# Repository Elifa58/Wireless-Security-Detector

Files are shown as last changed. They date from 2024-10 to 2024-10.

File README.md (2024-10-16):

# Wireless-Security-Detector
I designed a PCB described in a course I took on the Udemy platform in September 2022. With this course, I designed a PCB namely Wireless Security Detector.

In this project, I learned many things such as component selection criterias, creating my own 3D model, creating a template for the schematic page, working with the STM32CubeMx program, information about stackup and vias, information about differential lines, adding logos to the PCB, teardrops feature, creating variants, panelization and obtaining production outputs.

The requirements of the designed card are as follows:
The card should be able to work with 220V AC 50 Hz Turkey home network connection. There should be 12V DC and 5V DC power outputs that the user can use from the system. The system should be able to connect to the computer with a USB interface and transfer data. The system should be able to provide real-time clock information to the user. The system should be able to instantly transfer ambient temperature data to the user. The system should be able to send data to the user when a movement is detected. When a movement is detected, the user can receive an audio or visual warning if they wish. The system should have a security camera view in the environment where the movement will be detected. The system will also be able to send all data to the user with its Wi-Fi feature. The user will be able to intervene in the software running in the processor if they wish.

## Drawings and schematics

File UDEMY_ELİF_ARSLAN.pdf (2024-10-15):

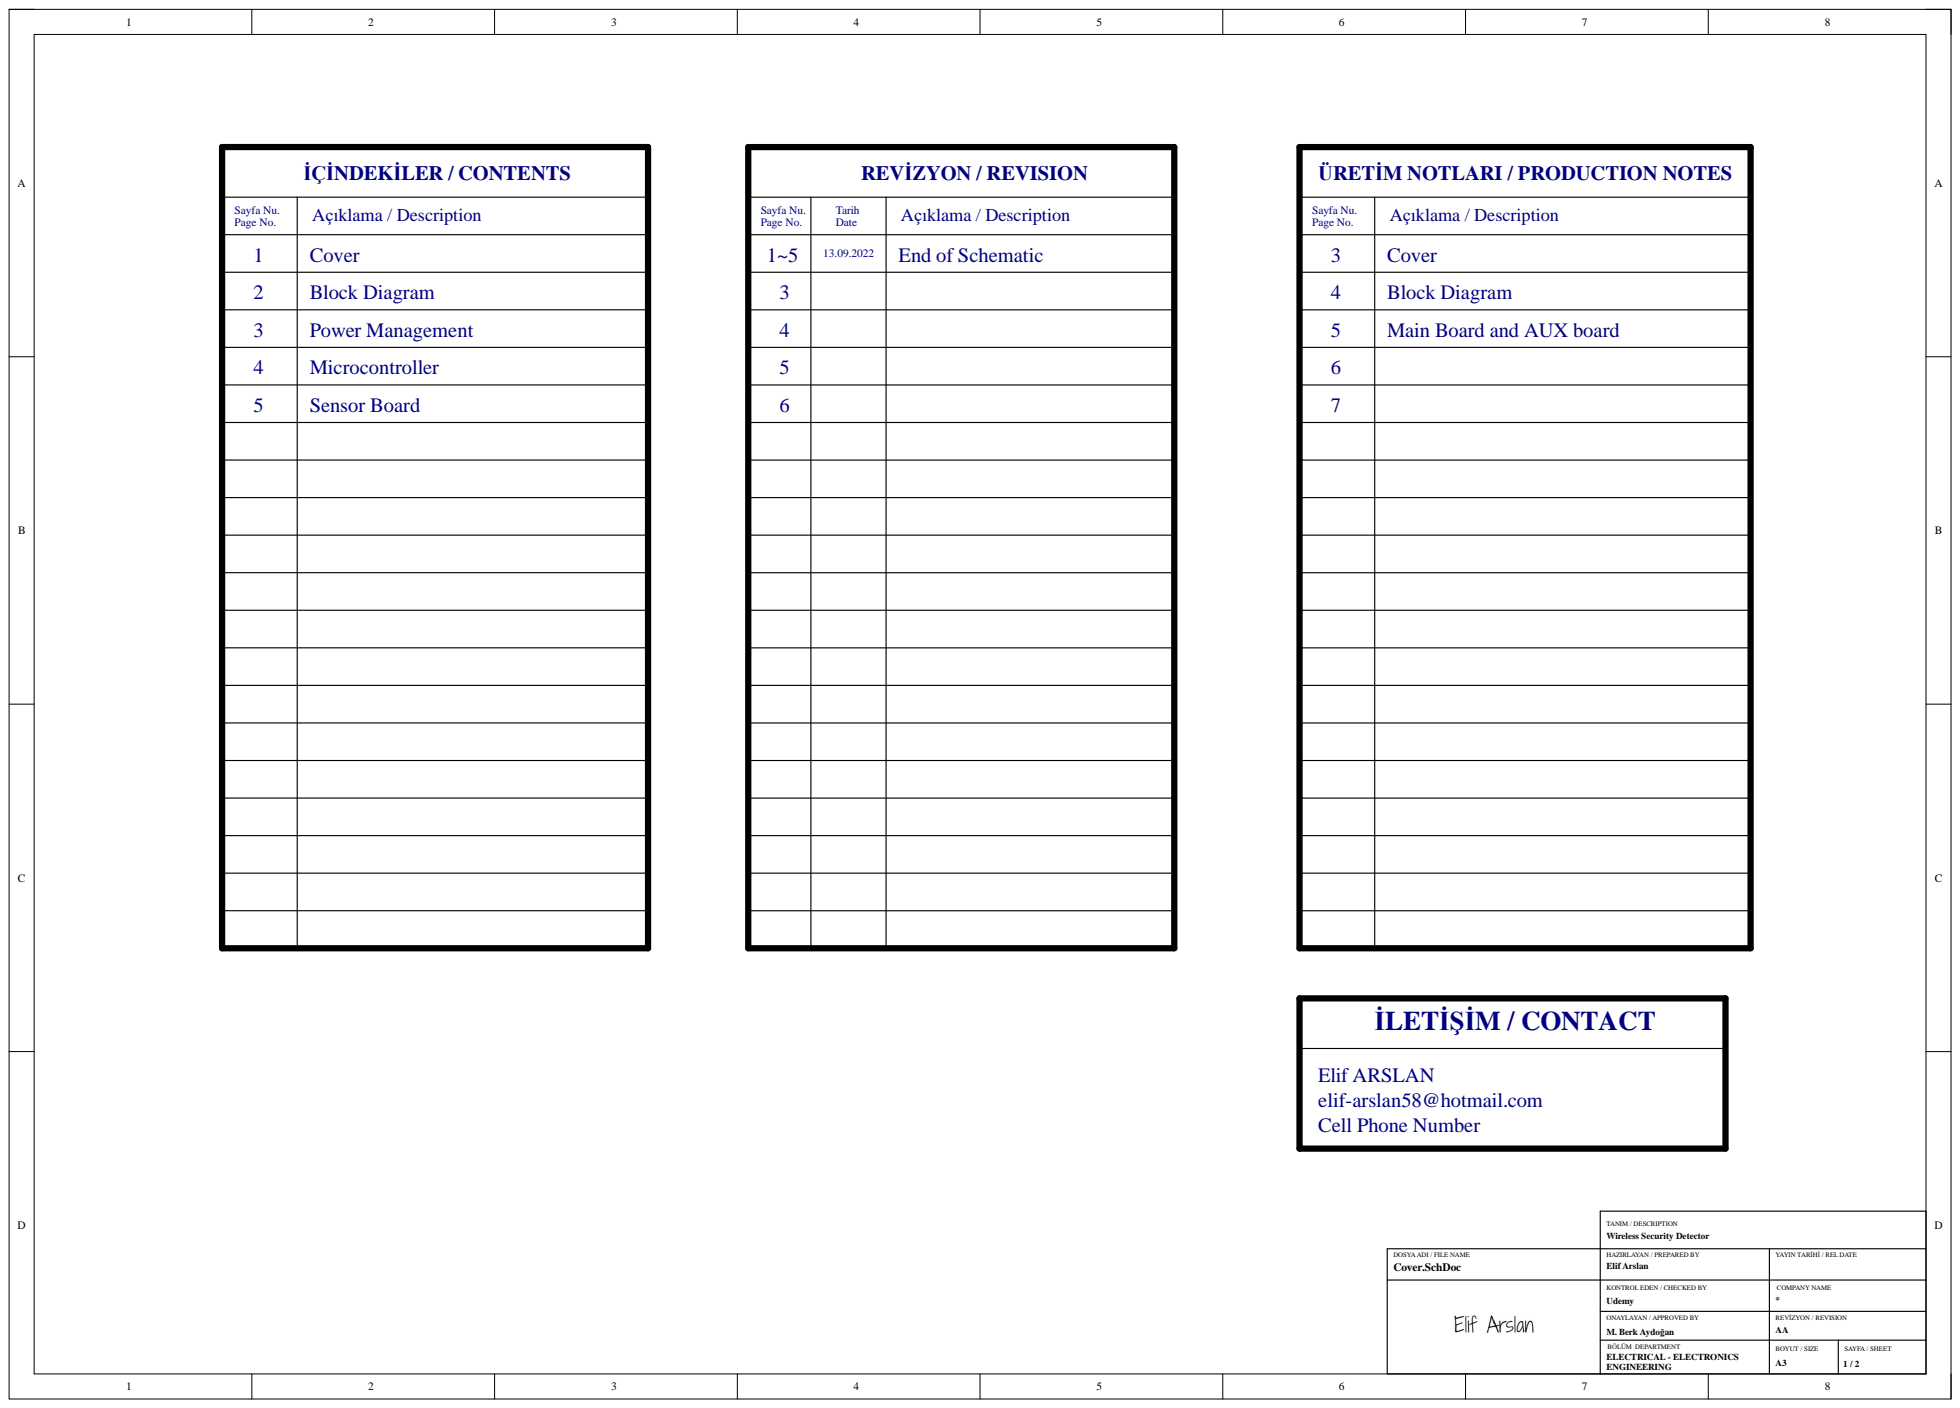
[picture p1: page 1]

ÜRETİM NOTLARI / PRODUCTION NOTES

Main Board and AUX board

DOSYA ADI / FILE NAME Cover.SchDoc | HAZIRLAYAN / PREPARED BY Elif Arslan | YAYIN TARİHİ / REL DATE

KONTROL EDEN / CHECKED BY Udemy | COMPANY NAME *

ONAYLAYAN / APPROVED BY M. Berk Aydoğan | REVİZYON / REVISION AA

BÖLÜM DEPARTMENT ELECTRICAL - ELECTRONICS ENGINEERING | BOYUT / SIZE A3 | SAYFA / SHEET 1 / 2

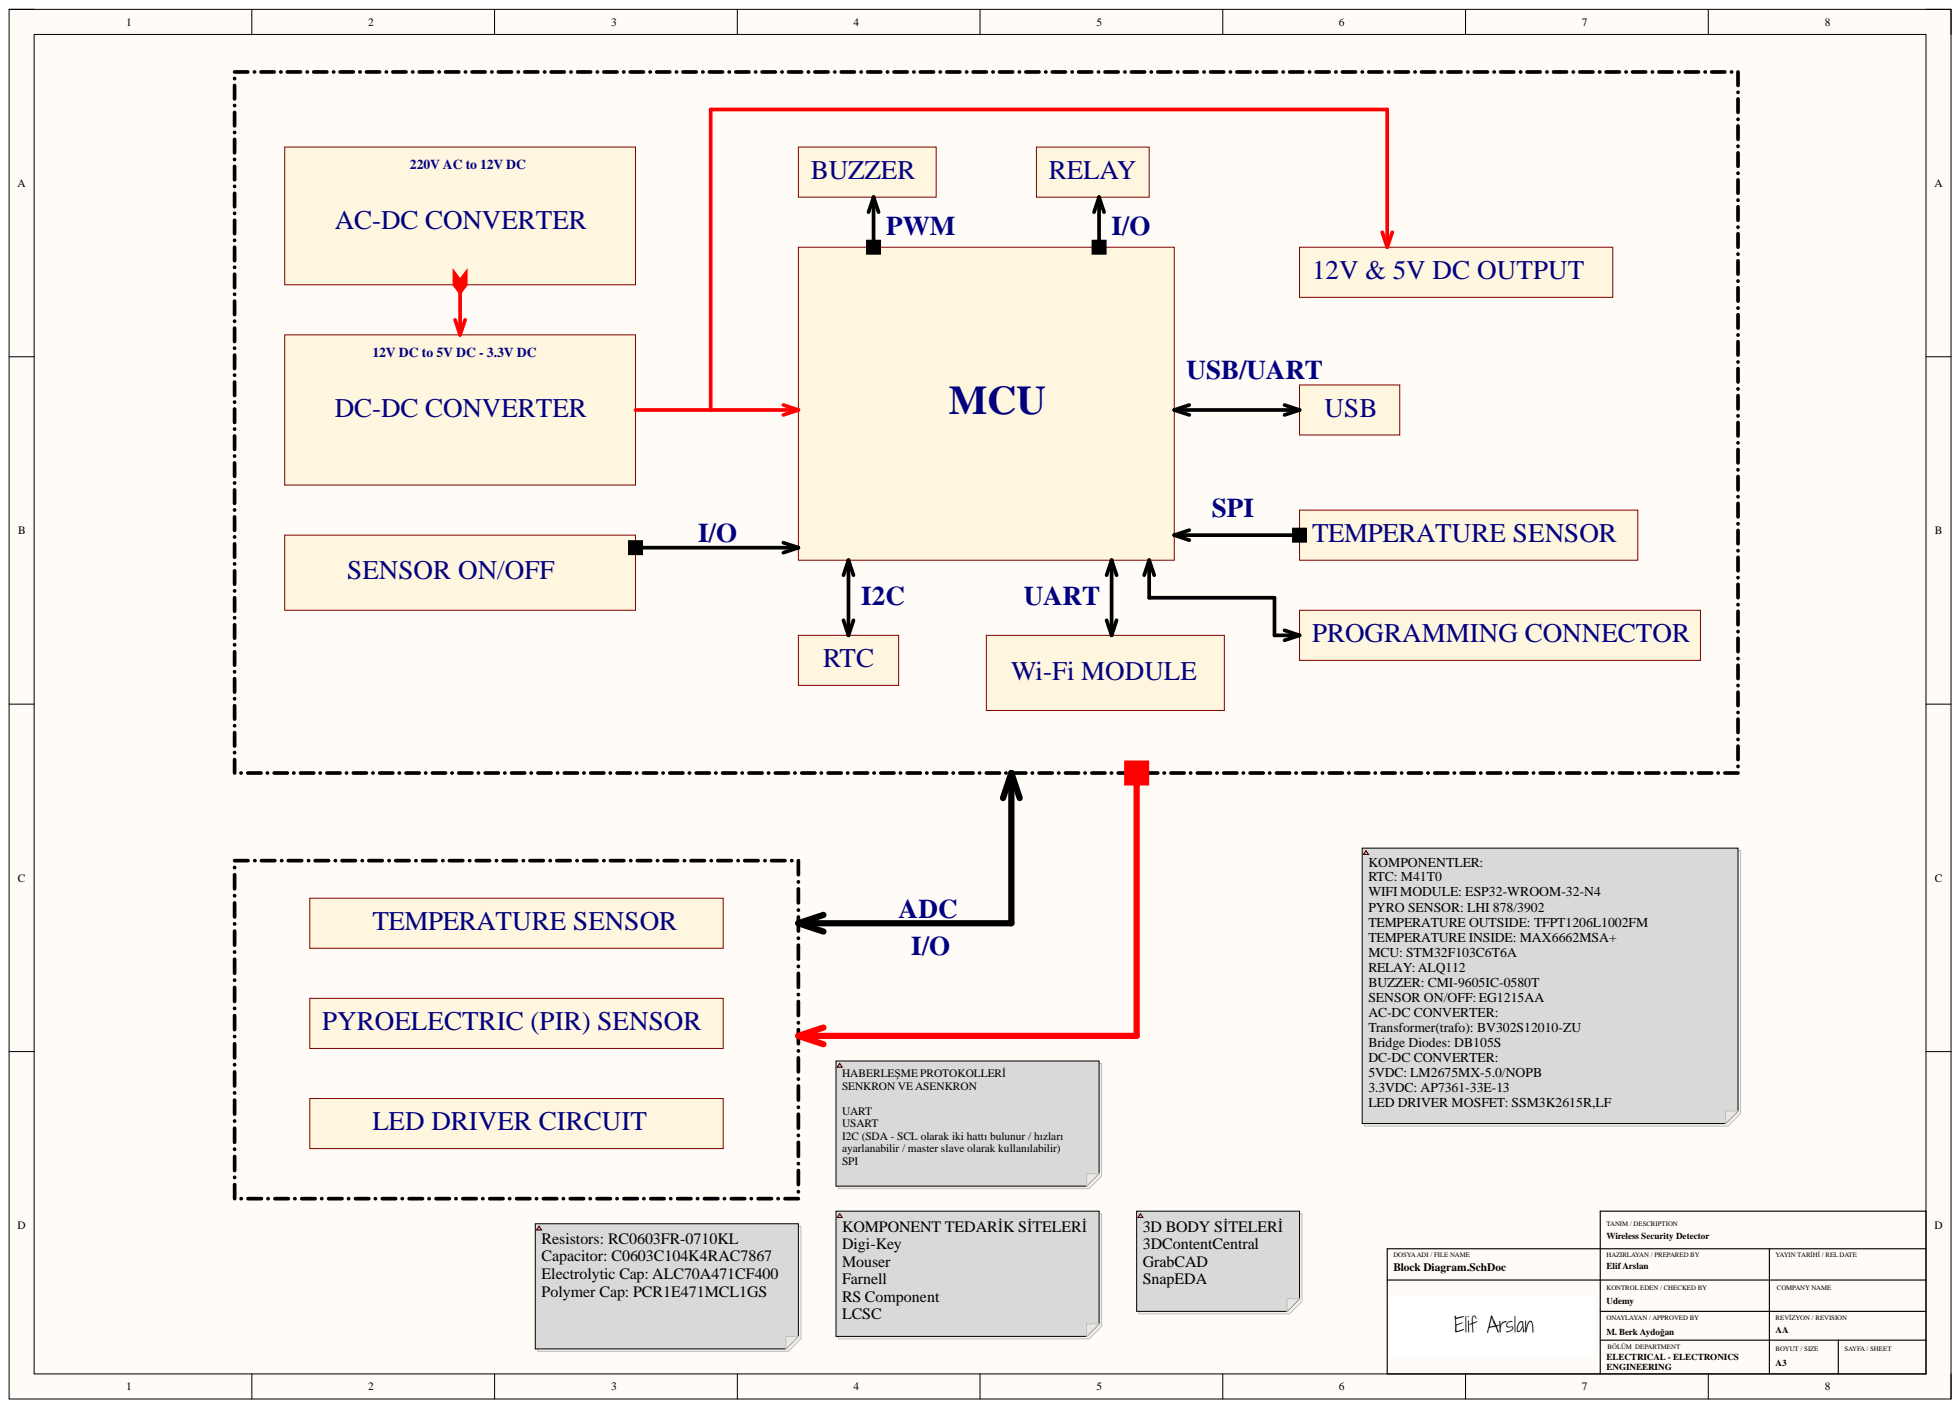
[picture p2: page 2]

KOMPONENTLER:
RTC: M41T0
WIFI MODULE: ESP32-WROOM-32-N4
PYRO SENSOR: LHI 878/3902
TEMPERATURE OUTSIDE: TFPT1206L1002FM
TEMPERATURE INSIDE: MAX6662MSA+
MCU: STM32F103C6T6A
RELAY: ALQ112
BUZZER: CMI-9605IC-0580T
SENSOR ON/OFF: EG1215AA
AC-DC CONVERTER:
Transformer(trafo): BV302S12010-ZU
Bridge Diodes: DB105S
DC-DC CONVERTER:
5VDC: LM2675MX-5.0/NOPB
3.3VDC: AP7361-33E-13
LED DRIVER MOSFET: SSM3K2615R,LF

UART
USART
I2C (SDA - SCL olarak iki hattı bulunur / hızları
ayarlanabilir / master slave olarak kullanılabilir)
SPI

DOSYA ADI / FILE NAME Block Diagram.SchDoc | HAZIRLAYAN / PREPARED BY Elif Arslan | YAYIN TARİHİ / REL DATE

KONTROL EDEN / CHECKED BY | COMPANY NAME

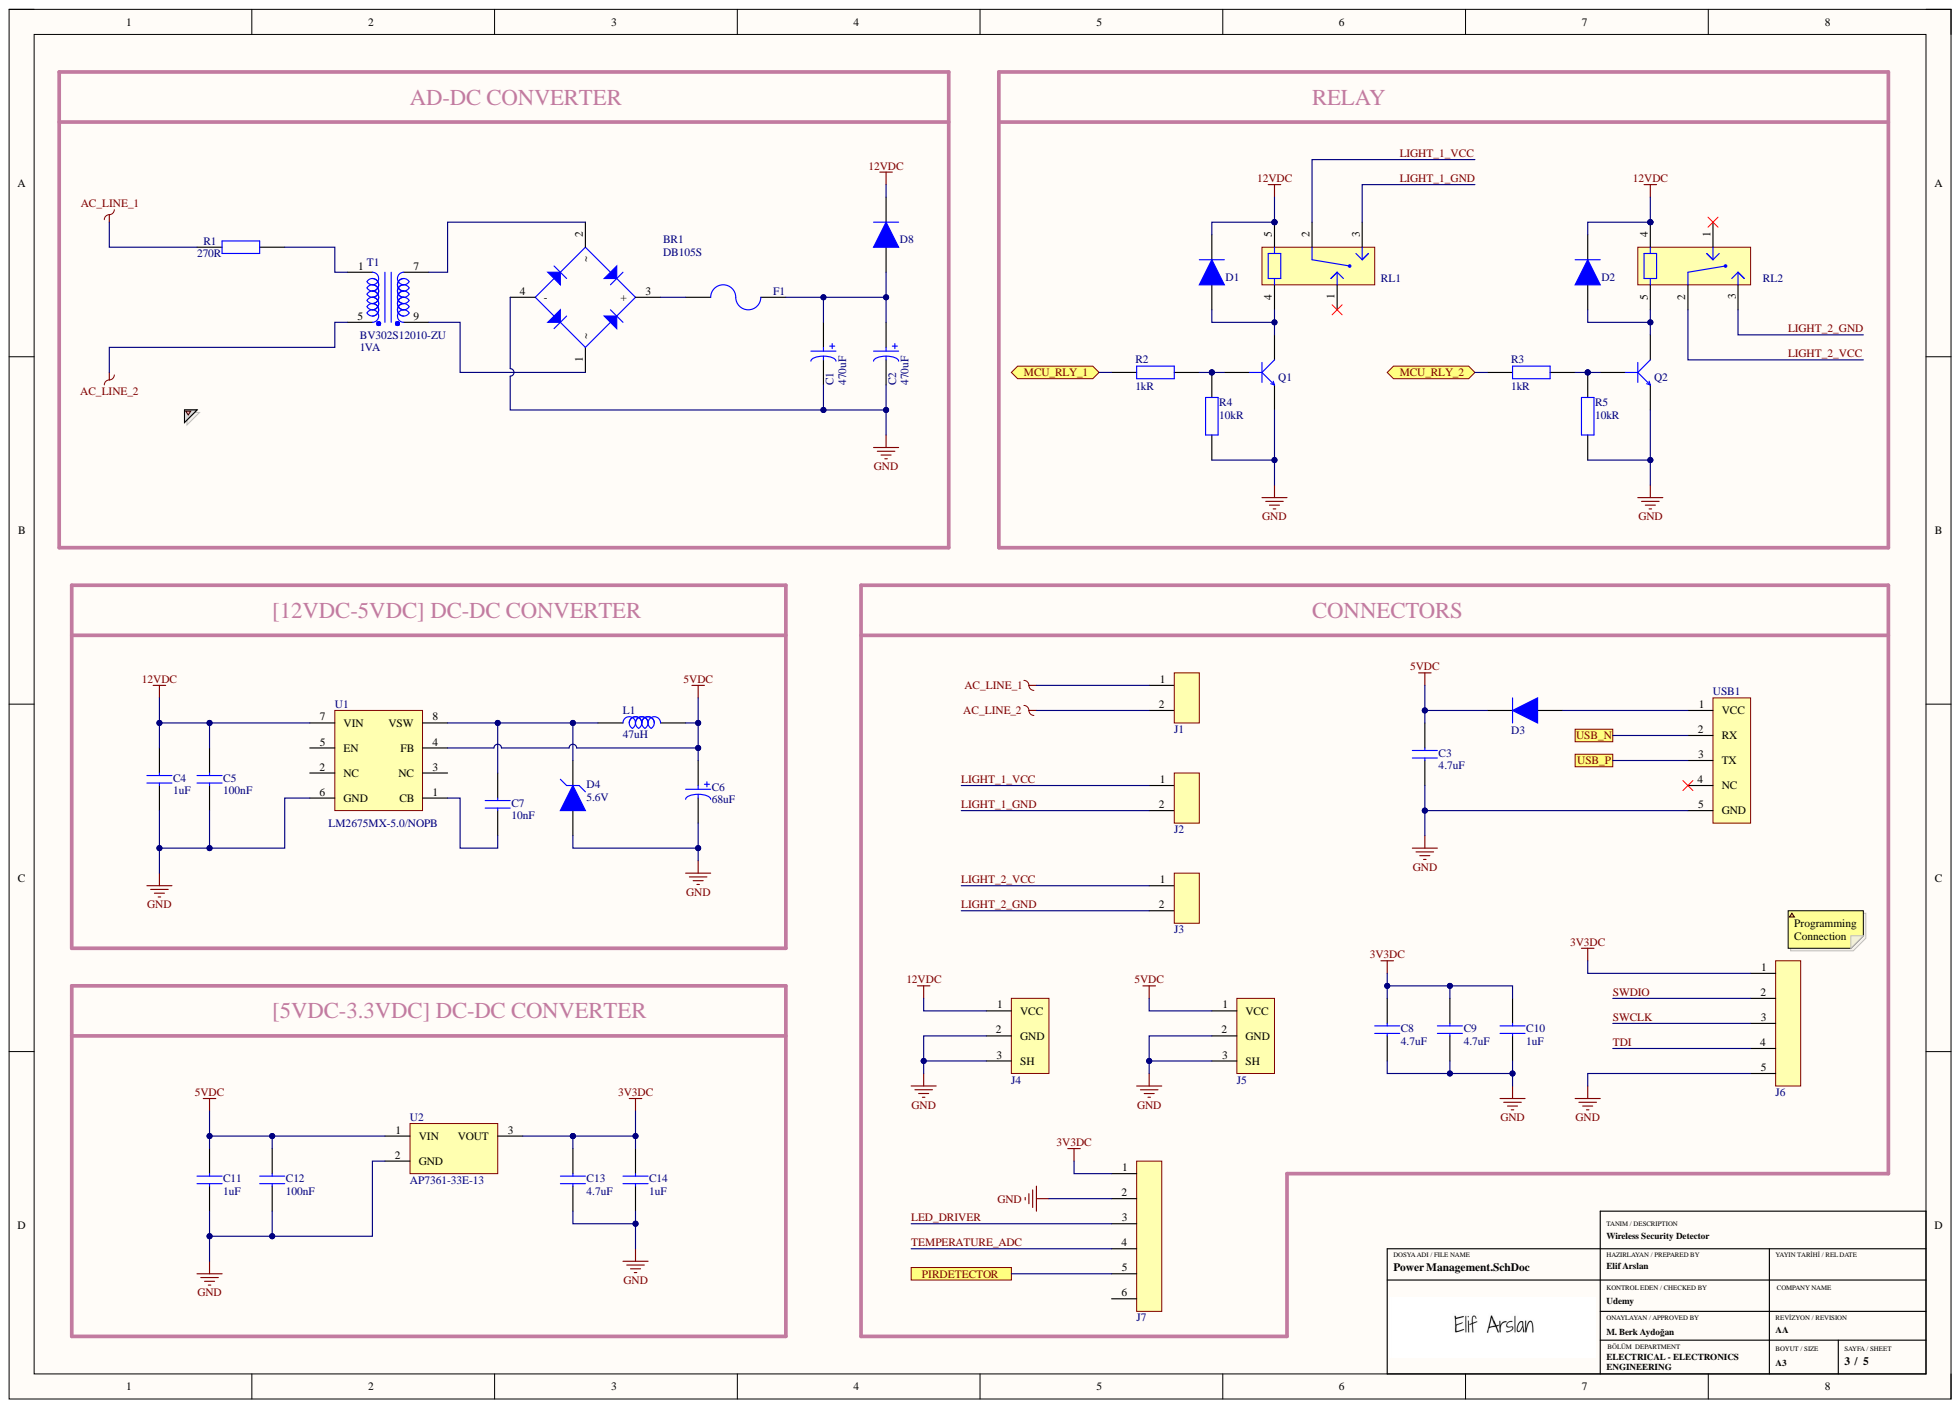
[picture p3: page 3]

USB_P | NC 4

KONTROL EDEN / CHECKED BY

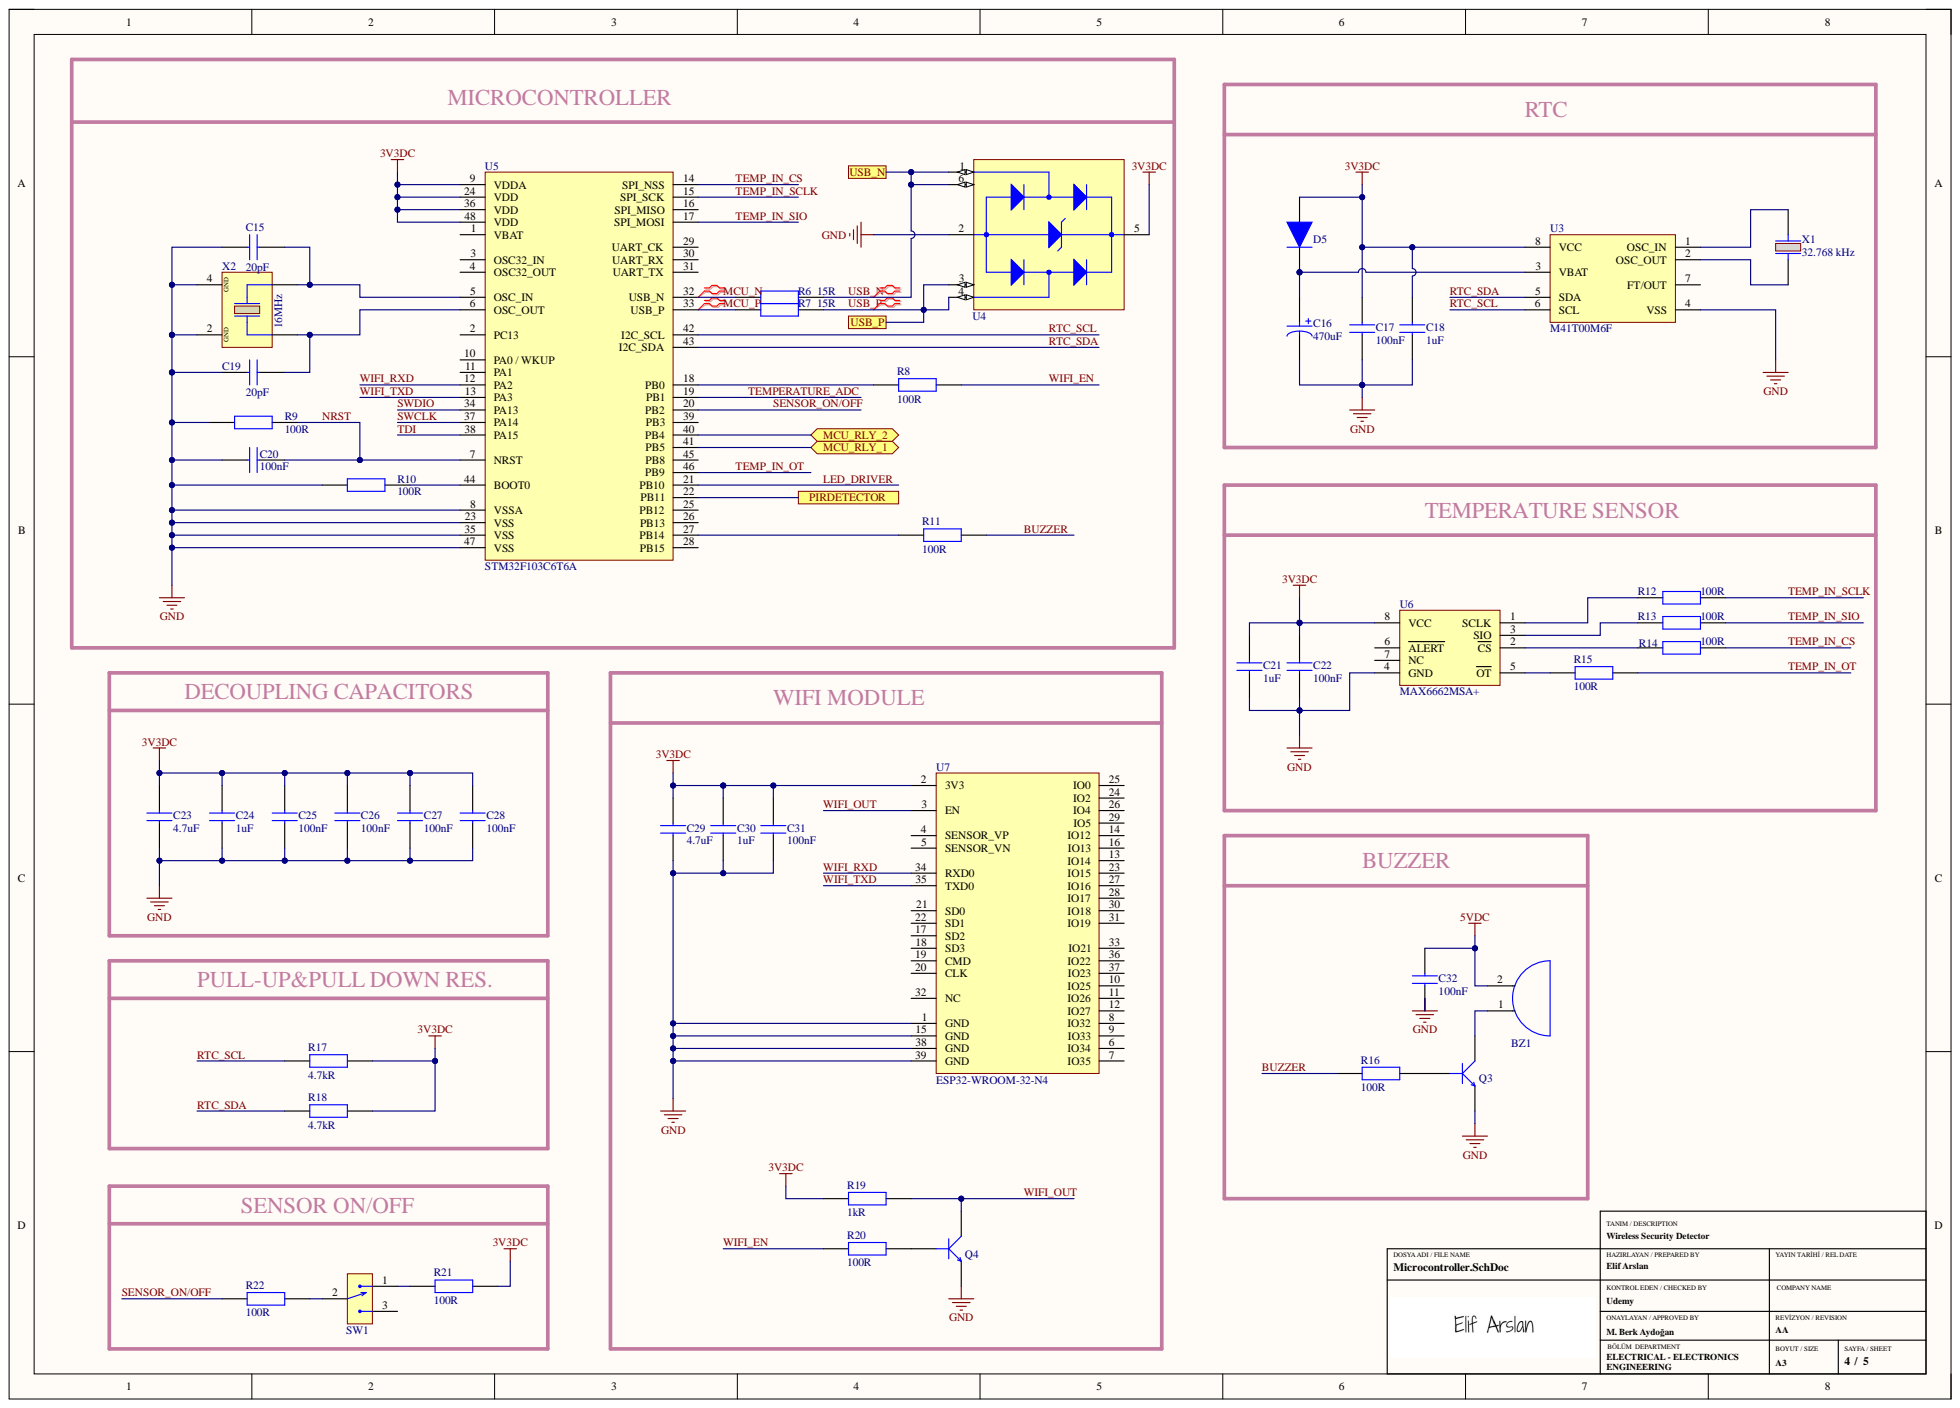
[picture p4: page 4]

PULL-UP&PULL DOWN RES.

DOSYA ADI / FILE NAME Microcontroller.SchDoc | HAZIRLAYAN / PREPARED BY Elif Arslan | YAYIN TARİHİ / REL DATE

KONTROL EDEN / CHECKED BY | COMPANY NAME

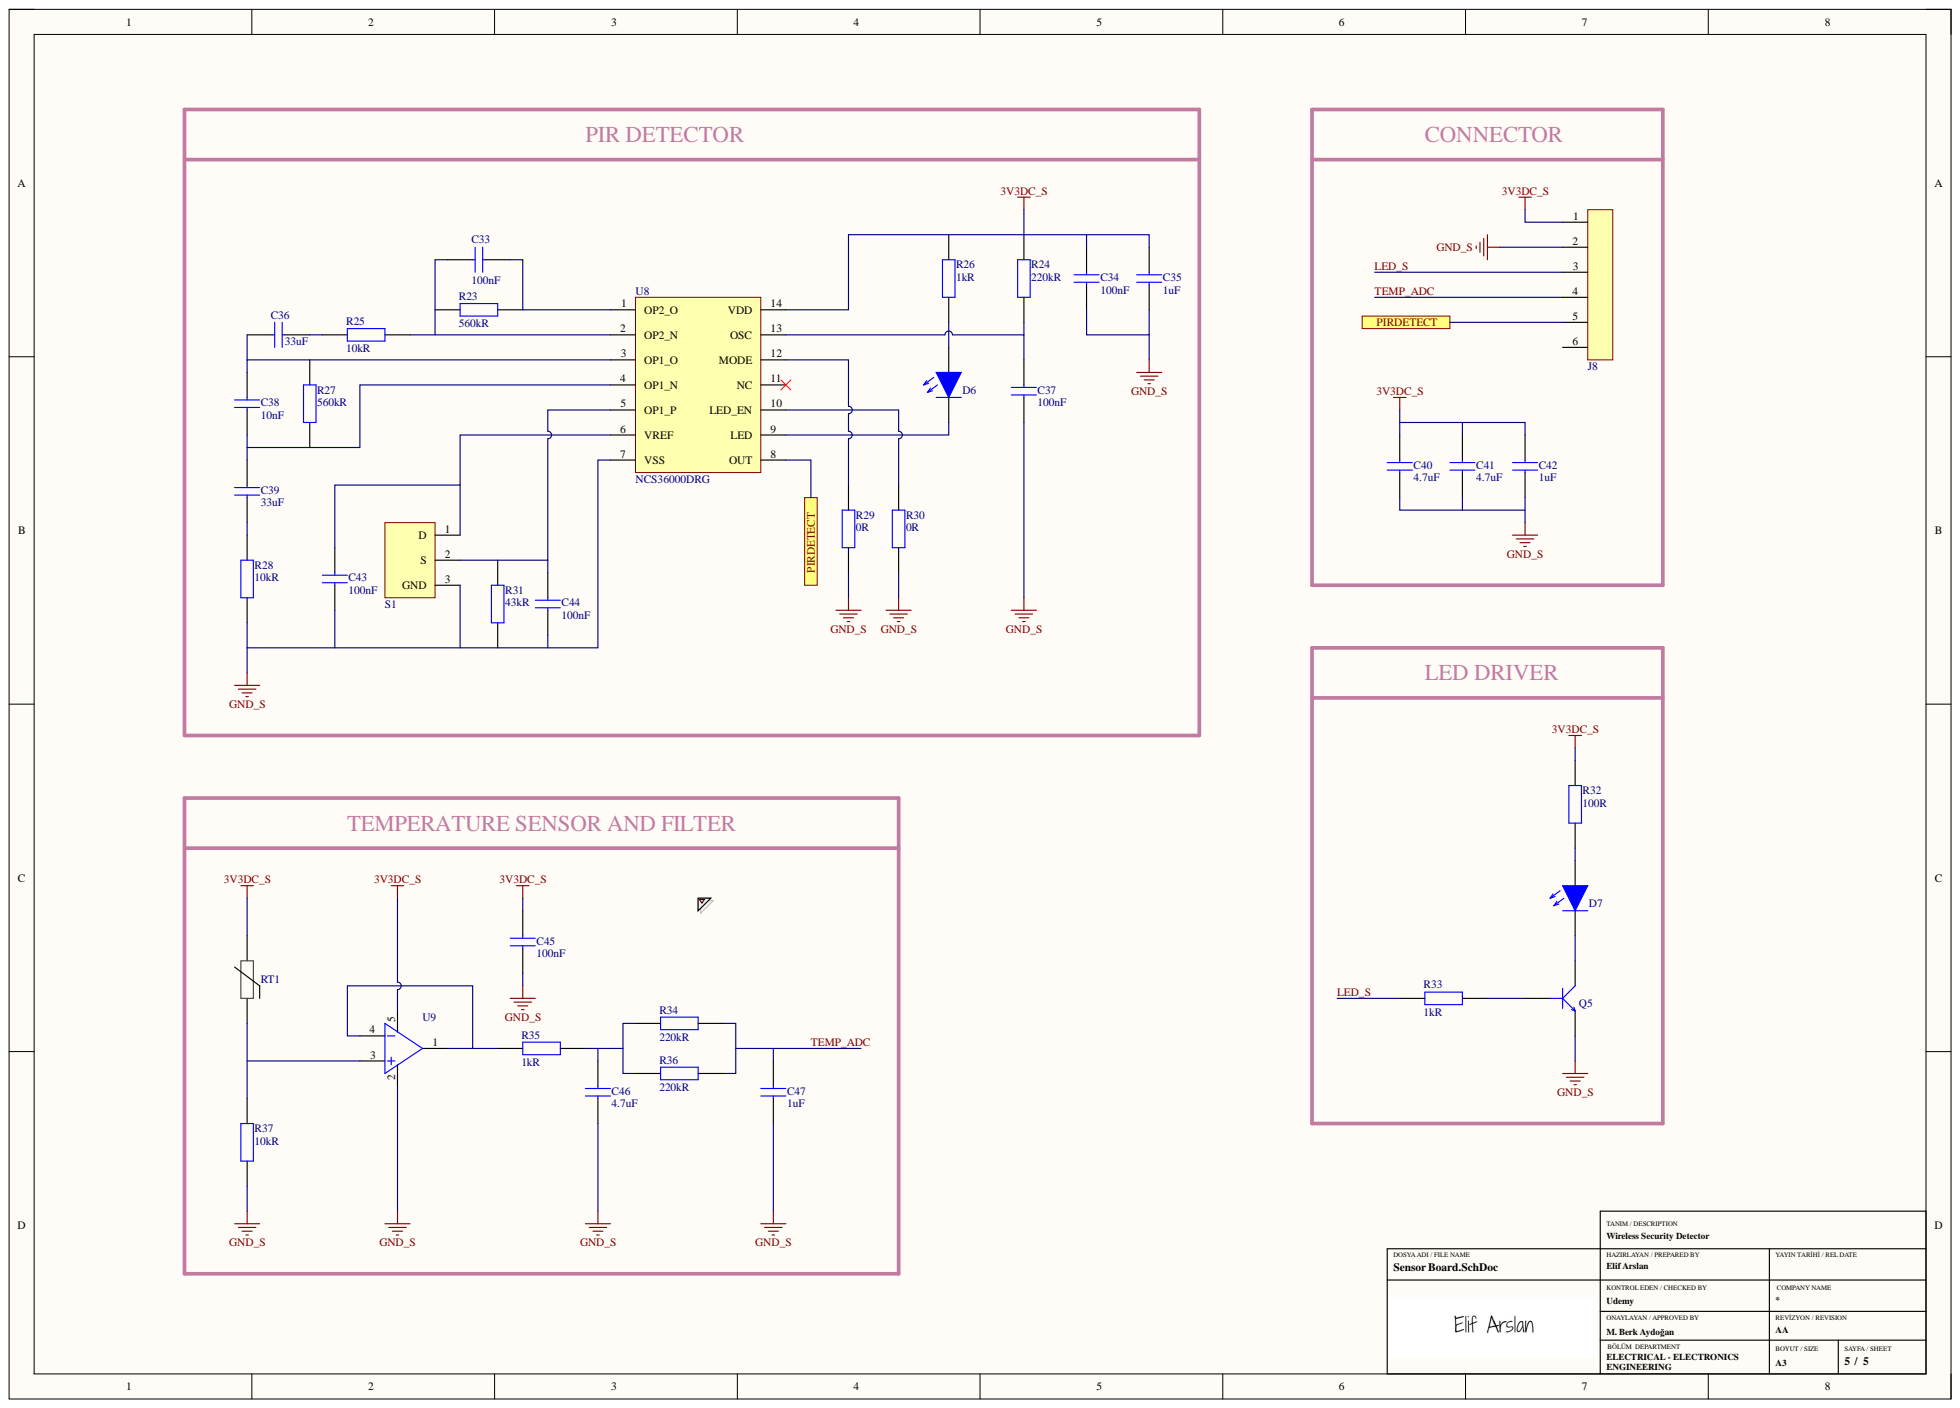
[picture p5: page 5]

TEMPERATURE SENSOR AND FILTER

D O S YA A DI / FIL E N A M E SensorBoard.SchDoc | H A ZIRL AYA N / PRE PARE D BY Elif Arslan | YAYIN TA R İ H İ / RE L D AT E

K O N TRO L E D E N / CH ECK E D BY Udem y | CO M PA N Y N A M E *

O N AY L AYA N / A P PRO V E D BY M. Berk Aydo ğan | İ RE V Z Y O N / RE VISIO N

B Ö LÜ M D E PA RT M E N T E L ECTRICAL - E L ECTRONICS ENGINE ERING | BO Y U T / SIZ E | S AY FA / S H E E T 5 / 5

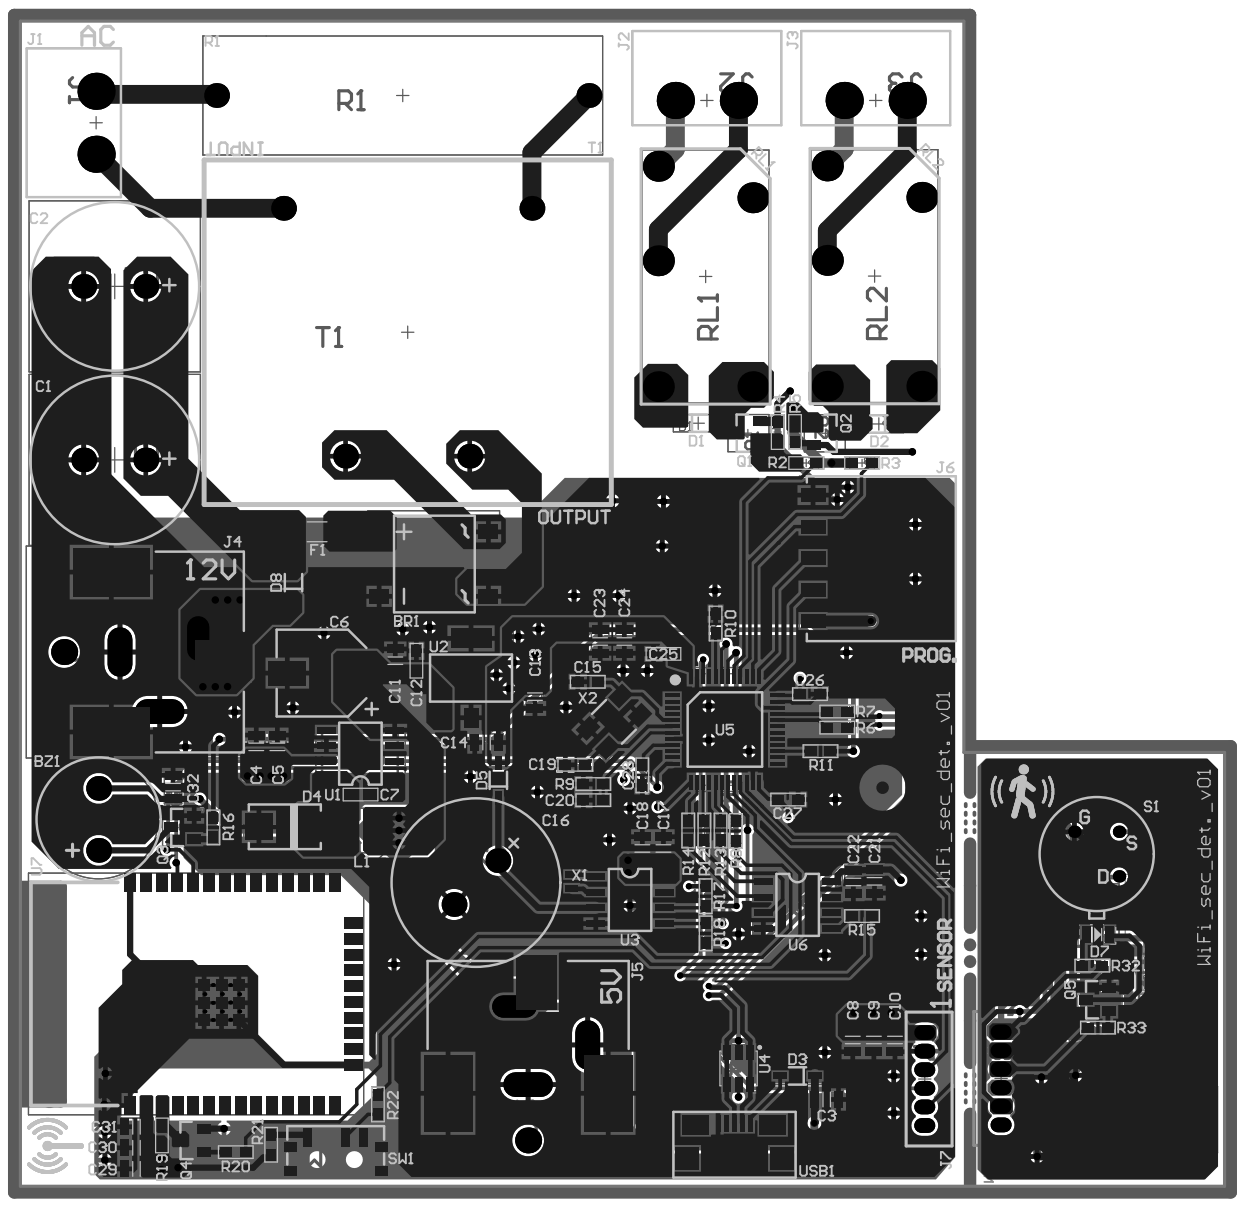
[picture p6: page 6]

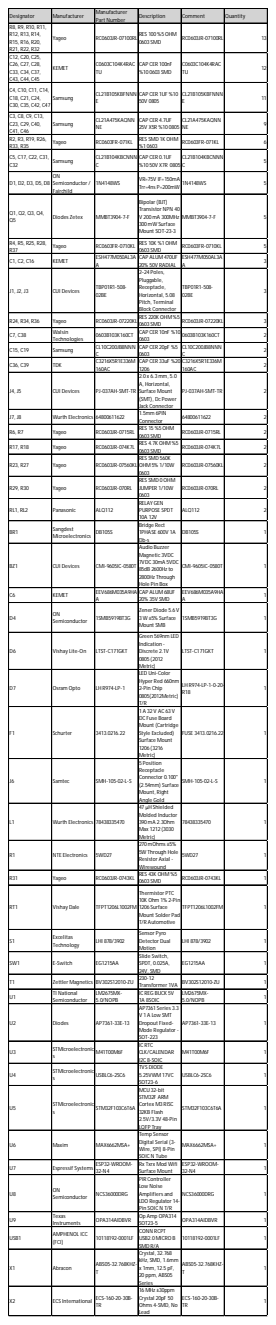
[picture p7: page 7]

Designator | Manufacturer | Manufacturer Part Number | Description | Comment | Quantity

R8, R9, R10, R11, R12, R13, R14, R15, R16, R20, R21, R22, R32 | Yageo | RC0603JR-07100RL RES 100 %5OHM | 0603 SMD | RC0603JR-07100RL | 13

C12, C20, C25, C26, C27, C28, C33, C34, C37, C43, C44, C45 | KEMET | C0603C104K4RAC TU | CAP CER 100nF %10 0603 SMD | C0603C104K4RAC TU | 12

C4, C10, C11, C14, C18, C21, C24, C30, C35, C42, C47 | Samsung | CL21B105KBFNNN E | CAP CER 1UF %10 50V 0805 | CL21B105KBFNNN E | 11

C3, C8, C9, C13, C23, C29, C40, C41, C46 | Samsung | CL21A475KAQNN NE | CAP CER 4.7UF 25V X5R %10 0805 | CL21A475KAQNN NE | | 9

R2, R3, R19, R26, R33, R35 | Yageo | RC0603FR-071KL | RES SMD 1K OHM %1 0603 | RC0603FR-071KL | | 6

C5, C17, C22, C31, C32 | Samsung | CL21B104KBCNNN C | CAP CER 0.1UF %10 50V X7R 0805 | CL21B104KBCNNN C | | 5

D1, D2, D3, D5, D8 | ON Semiconductor / Fairchild | 1N4148WS | VR=75V IF=150mA Trr=4ns P=200mW | 1N4148WS | | 5

Q1, Q2, Q3, Q4, Q5 | Diodes Zetex | MMBT3904-7-F | Bipolar (BJT) Transistor NPN 40 V 200mA 300MHz 300mW Surface Mount SOT-23-3 | MMBT3904-7-F | | 5

R4, R5, R25, R28, R37 | Yageo | RC0603FR-0710KL | RES 10K %1OHM 0603 SMD | RC0603FR-0710KL | | 5

J1, J2, J3 | CUI Devices | TBP01R1-508-02BE | 2~24 Poles, Pluggable, Receptacle, Horizontal, 5.08 Pitch, Terminal Block Connector | TBP01R1-508-02BE | | 3

C1, C2, C16 | KEMET | ESH477M050AL3A A | CAP ALUM 470UF 20% 50V RADIAL | ESH477M050AL3A A | | 3

R24, R34, R36 | Yageo | RC0603JR-07220KL RES 220K OHM %5 | 0603 SMD | RC0603JR-07220KL | | 3

C7, C38 | Walsin Technologies | 0603B103K160CT | CAP CER 10nF %10 0603 | 0603B103K160CT | | 2

C15, C19 | Samsung | CL10C200JB8NNN C | CAP CER 20pF %5 0603 | CL10C200JB8NNN C | | 2

C36, C39 | TDK | C3216X5R1E336M 160AC | CAP CER 33uF %20 1206 | C3216X5R1E336M 160AC | | 2

J4, J5 | CUI Devices | PJ-037AH-SMT-TR | 2.0 x 6.3mm, 5.0 A, Horizontal, Surface Mount (SMT), Dc Power Jack Connector | PJ-037AH-SMT-TR | | 2

J7, J8 | Wurth Electronics | 64800611622 | 1.5mm 6PIN Connector | 64800611622 | | 2

R6, R7 | Yageo | RC0603JR-0715RL | RES 15 %5OHM 0603 SMD | RC0603JR-0715RL | | 2

R17, R18 | Yageo | RC0603JR-074K7L | RES 4.7K OHM %5 0603 SMD | RC0603JR-074K7L | | 2

R23, R27 | Yageo | RC0603JR-07560KL | RES SMD 560K OHM 5% 1/10W 0603 | RC0603JR-07560KL | | 2

R29, R30 | Yageo | RC0603JR-070RL | RES SMD 0OHM JUMPER 1/10W 0603 | RC0603JR-070RL | | 2

RL1, RL2 | Panasonic | ALQ112 | RELAY GEN PURPOSE SPDT 10A 12V | ALQ112 | | 2

BR1 | Sangdest Microelectronics | DB105S | Bridge Rect 1PHASE 600V 1A Db-s | DB105S | | 1
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
